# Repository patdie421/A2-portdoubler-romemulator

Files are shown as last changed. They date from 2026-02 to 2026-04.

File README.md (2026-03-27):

This card provide 2 functionalities :  
- duplicates the slot it uses into two horizontal slots (usefull in slot 7). I designed it to be able to use an A2DVI interface on Apple II computers where all the slots are occupied.  
- ROM emulation card (https://mirrors.apple2.org.za/ftp.apple.asimov.net/documentation/hardware/schematics/rom_emulator_card_050-0009-01_schematic.pdf). A friend ask me for a card capable of running Adrian Black's Deadtest ROM (https://github.com/misterblack1/appleII_deadtest). Since I had space on my slot splitter, I simply added three chips, and that was it. This first version is designed to use only the Deadtest ROM. Current restriction :
  - it did'nt allow to be controled by softwitch  
  - DMA IN/OUT are not supported (not needed when used in slot 7)  

  A version of the card currently under development will provide all the functionalities of a ROM card  
# Slot doubler  
This card is designed to allow the installation of two cards in a single slot. Although it can be installed in any slot, it is most effectively used as a splitter in slot 7. Since the two connectors are wired in parallel, not all card combinations are possible.
## kinds of Apple II cards
We can identify 3 kinds of cards :
- basic card : use soft switches, 16 addresses 0xC080+n\*0x10 to 0xC08F+n\*0x10, n=1 to 7, to interact whith the system. The card is activated by "Device Select" line.
- card with firmware locate at Cn00-CnFF (n=1 to 7), the "I/O Select" activated this kind of card when the firmware page is read or write. Most of this cards (if not all) use also soft switches at addresses C0N0x.  
- card "monitoring" the address bus (does not use device selection or I/O selection).  

## possible combinaisons

Different factors limit possible combinations :
- kind of card
- DMA or Interrupts
Other factors limit this combination, including the use of DMA and interrupt lines (/NMI and /INT).  
Before trying to install 2 cards in the doubled slots you have to know witch kind of cards you have.  

## working (tested) combinaisons
(to be done)

(usefull information can be fund here : https://grokipedia.com/page/apple_ii_peripheral_cards)

# Rom emulation card
The rom is activated when a jumper is set on JP4. Current version can only be used for Apple II deadtest ROM.  
Work is in progress to emulate all functionalities of Apple Rom Emulator Card (050-0009-01)  (https://mirrors.apple2.org.za/Apple%20II%20Documentation%20Project/Interface%20Cards/ROM%20Cards/Apple%20ROM%20Emulator%20Card/Photos/Apple%20ROM%20Card%20with%20ROM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))

2764 or 27128 Eprom (or pinout equivalent) can be used. Check Adrian's documentation for burning the ROM. Not that for 8K ROM (2764) you have to load into address $1800 or for 16K ROM (27128) to $3800.

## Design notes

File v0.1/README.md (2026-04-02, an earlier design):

~~Tested, working.~~ Issues were reported. Debugging in progress (thanks Daniel)  
Warning: Installation in some IIe will be difficult for card in upper slot.

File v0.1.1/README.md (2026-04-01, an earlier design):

Update connector positions  
  
 Not tested now

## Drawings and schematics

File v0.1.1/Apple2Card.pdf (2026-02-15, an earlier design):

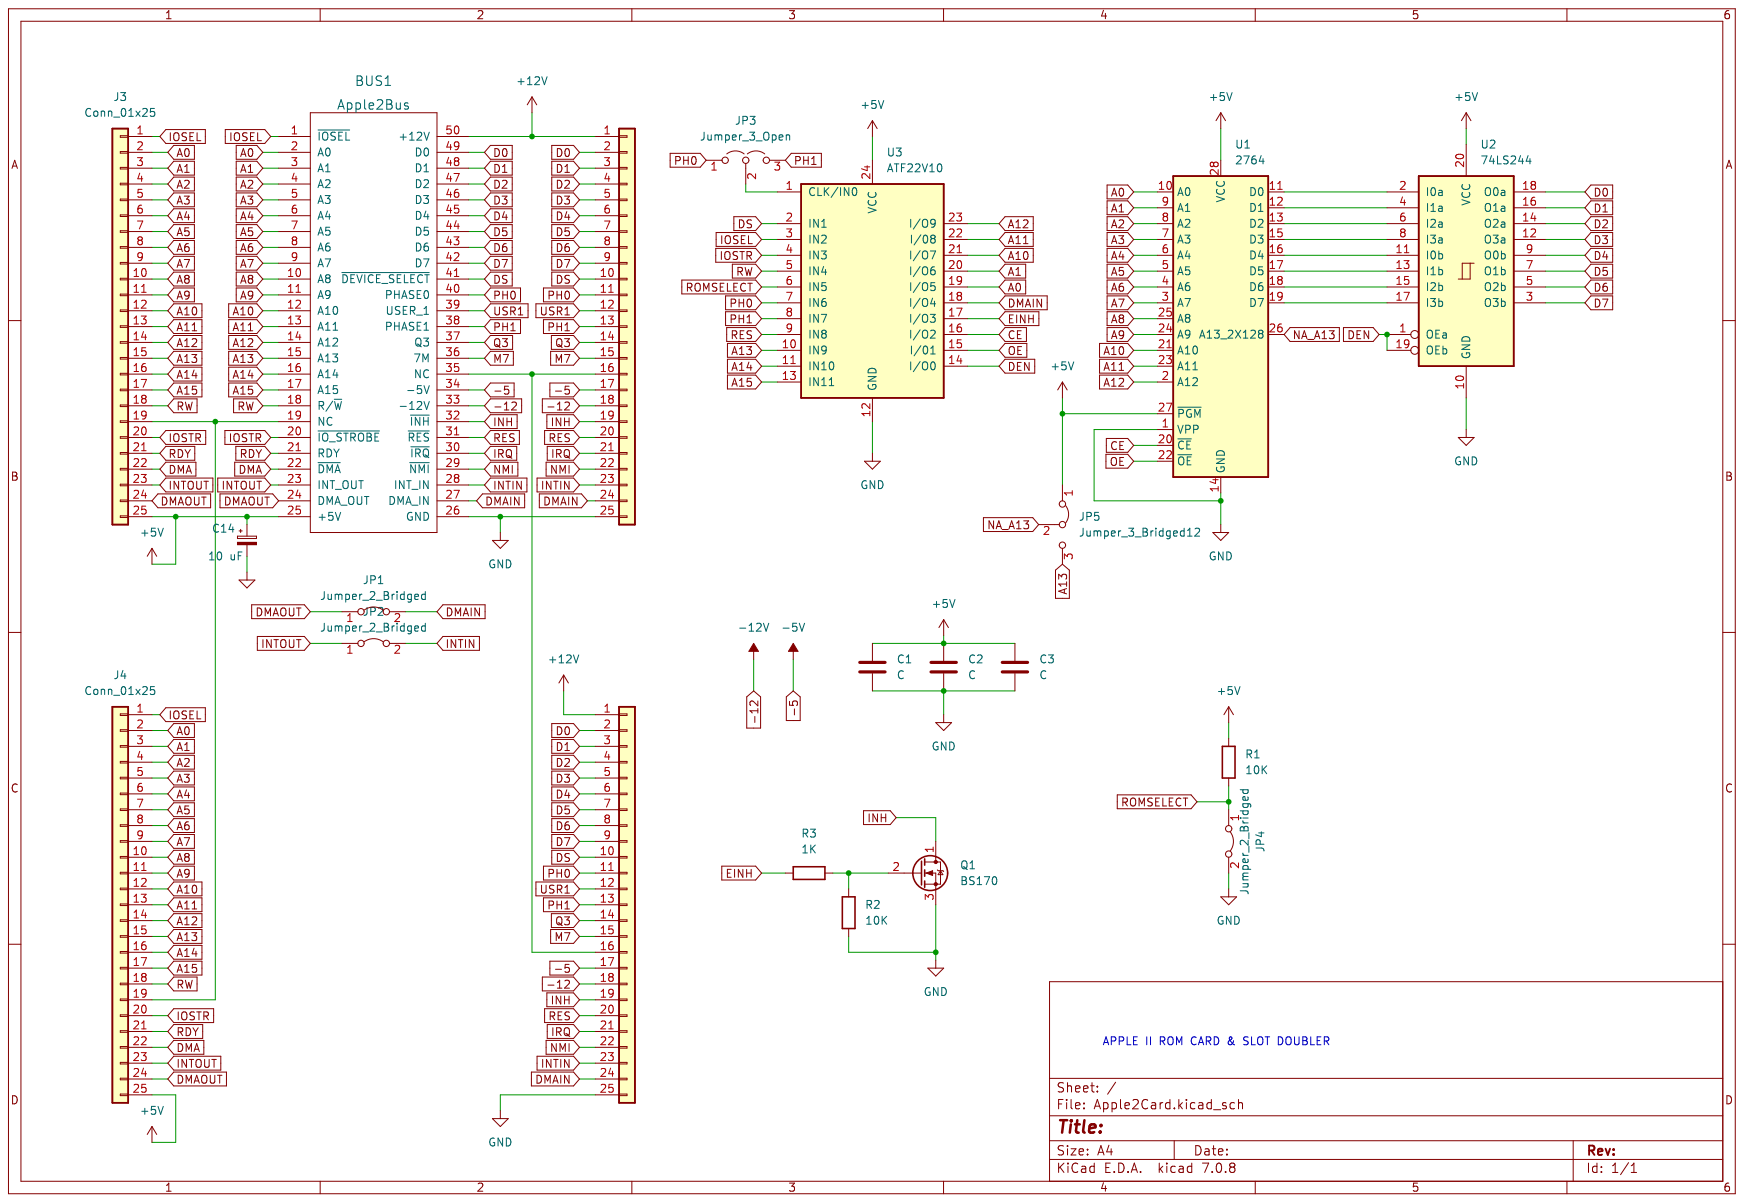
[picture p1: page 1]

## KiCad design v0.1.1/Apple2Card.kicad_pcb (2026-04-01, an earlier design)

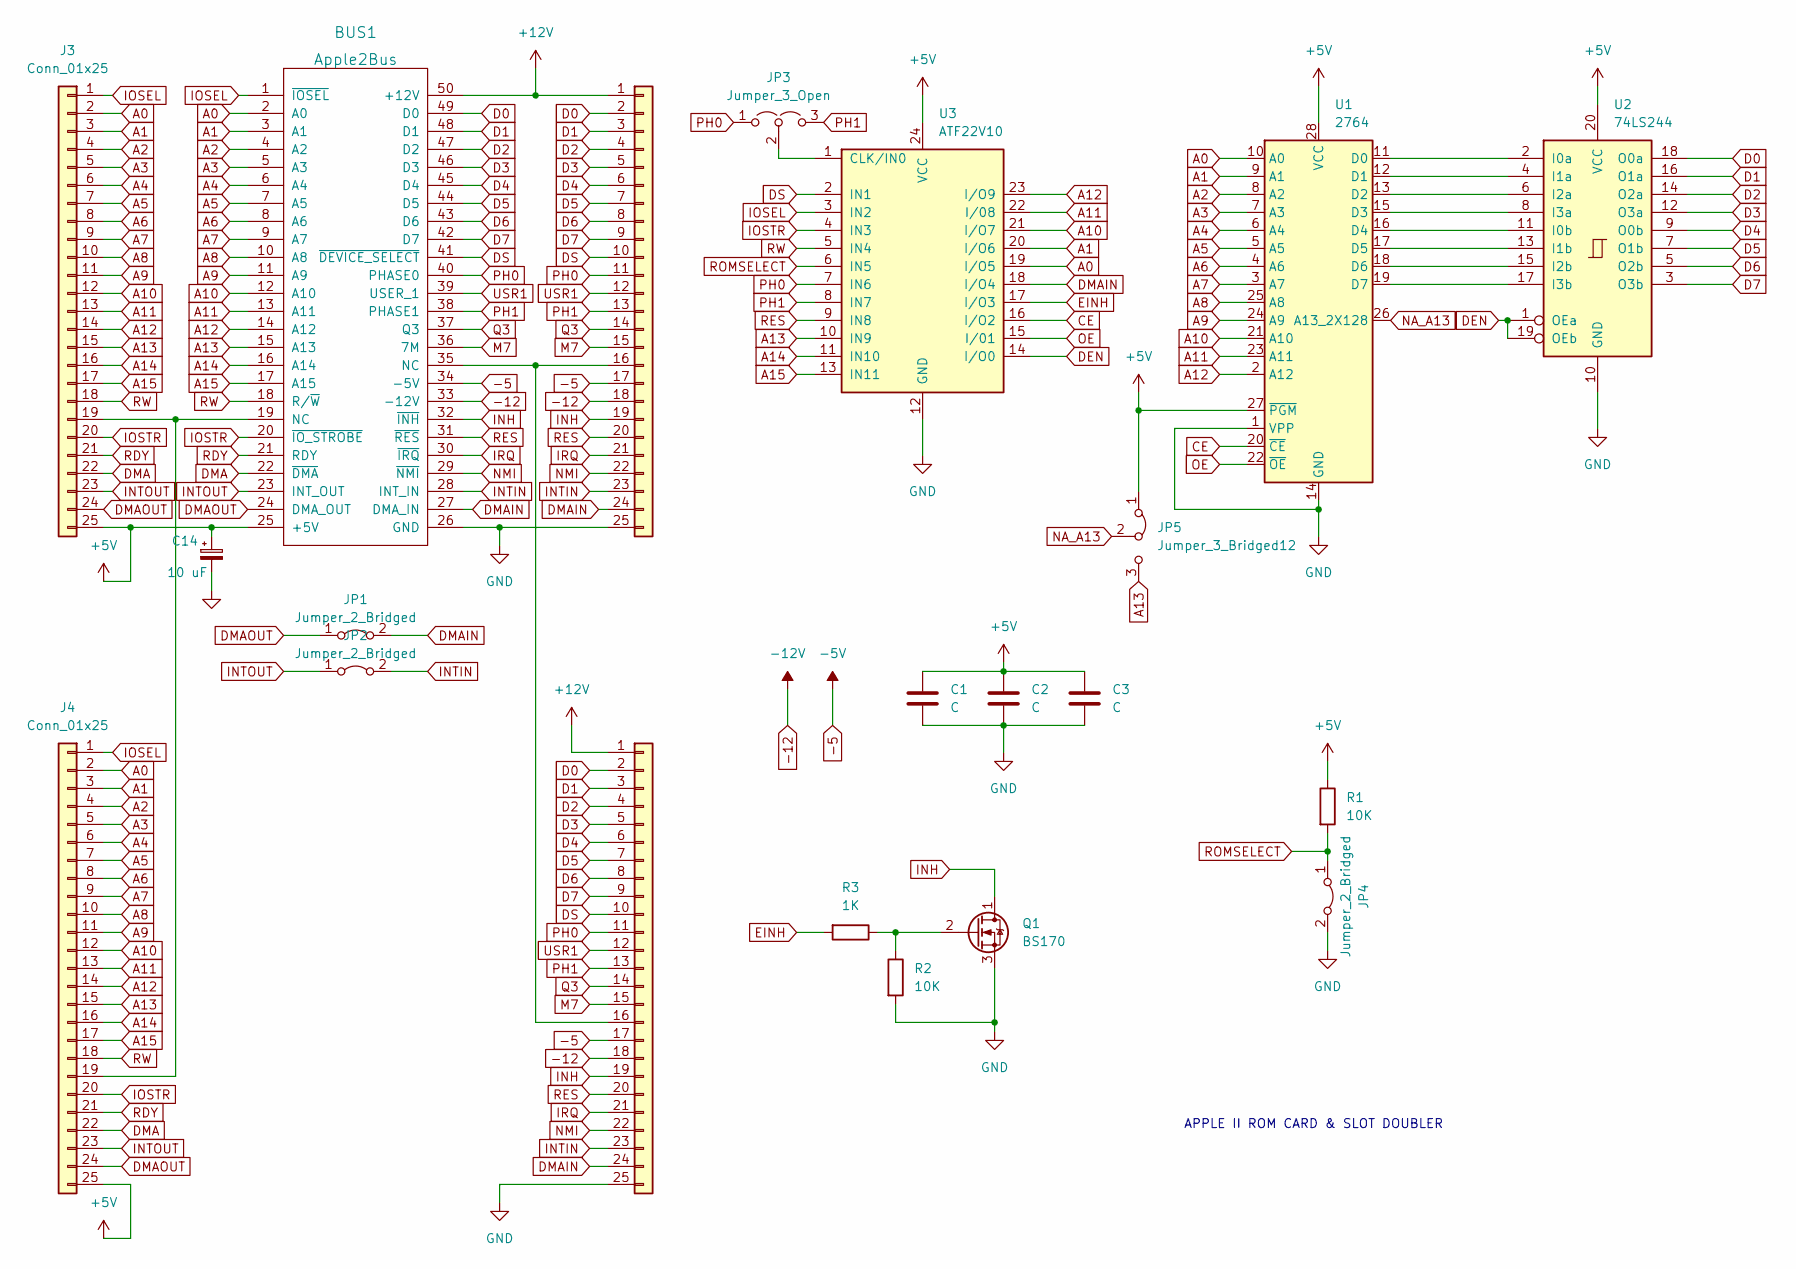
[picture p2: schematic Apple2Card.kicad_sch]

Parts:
BUS1: Apple2Bus; Apple2Slot
C1, C2, C3: C; C_Disc_D4.7mm_W2.5mm_P5.00mm
C14: 10 uF; CP_Radial_D5.0mm_P2.50mm
J1, J2, J3, J4: Conn_01x25; PinHeader_1x25_P2.54mm_Vertical
JP1, JP2, JP4: Jumper_2_Bridged; PinHeader_1x02_P2.54mm_Vertical
JP3: Jumper_3_Open; PinHeader_1x03_P2.54mm_Vertical
JP5: Jumper_3_Bridged12; SolderJumper-3_P1.3mm_Bridged12_RoundedPad1.0x1.5mm
Q1: BS170; TO-92_Inline
R1, R2: 10K; R_Axial_DIN0204_L3.6mm_D1.6mm_P7.62mm_Horizontal
R3: 1K; R_Axial_DIN0204_L3.6mm_D1.6mm_P7.62mm_Horizontal
U1: 2764; DIP-28_W15.24mm
U2: 74LS244; DIP-20_W7.62mm_Socket
U3: ATF22V10; DIP-24_W7.62mm_Socket

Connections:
+5V: BUS1.25 (+5V), C1.1, C2.1, C3.1, C14.1, J3.25, J4.25, JP5.1 (A), R1.1, U1.27 (~PGM), U1.28 (VCC), U2.20 (VCC), U3.24 (VCC)
+12V: BUS1.50 (+12V), J1.1, J2.1
-5: BUS1.34 (-5V), J1.17, J2.17
-12: BUS1.33 (-12V), J1.18, J2.18
A0: BUS1.2 (A0), J3.2, J4.2, U1.10 (A0), U3.19 (I/O5)
A1: BUS1.3 (A1), J3.3, J4.3, U1.9 (A1), U3.20 (I/O6)
A2: BUS1.4 (A2), J3.4, J4.4, U1.8 (A2)
A3: BUS1.5 (A3), J3.5, J4.5, U1.7 (A3)
A4: BUS1.6 (A4), J3.6, J4.6, U1.6 (A4)
A5: BUS1.7 (A5), J3.7, J4.7, U1.5 (A5)
A6: BUS1.8 (A6), J3.8, J4.8, U1.4 (A6)
A7: BUS1.9 (A7), J3.9, J4.9, U1.3 (A7)
A8: BUS1.10 (A8), J3.10, J4.10, U1.25 (A8)
A9: BUS1.11 (A9), J3.11, J4.11, U1.24 (A9)
A10: BUS1.12 (A10), J3.12, J4.12, U1.21 (A10), U3.21 (I/O7)
A11: BUS1.13 (A11), J3.13, J4.13, U1.23 (A11), U3.22 (I/08)
A12: BUS1.14 (A12), J3.14, J4.14, U1.2 (A12), U3.23 (I/O9)
A13: BUS1.15 (A13), J3.15, J4.15, JP5.3 (B), U3.10 (IN9)
A14: BUS1.16 (A14), J3.16, J4.16, U3.11 (IN10)
A15: BUS1.17 (A15), J3.17, J4.17, U3.13 (IN11)
CE: U1.20 (~CE), U3.16 (I/O2)
D0: BUS1.49 (D0), J1.2, J2.2, U2.18 (O0a)
D1: BUS1.48 (D1), J1.3, J2.3, U2.16 (O1a)
D2: BUS1.47 (D2), J1.4, J2.4, U2.14 (O2a)
D3: BUS1.46 (D3), J1.5, J2.5, U2.12 (O3a)
D4: BUS1.45 (D4), J1.6, J2.6, U2.9 (O0b)
D5: BUS1.44 (D5), J1.7, J2.7, U2.7 (O1b)
D6: BUS1.43 (D6), J1.8, J2.8, U2.5 (O2b)
D7: BUS1.42 (D7), J1.9, J2.9, U2.3 (O3b)
DEN: U2.1 (OEa), U2.19 (OEb), U3.14 (I/O0)
DMA: BUS1.22 (~DMA), J3.22, J4.22
DMAIN: BUS1.27 (DMA_IN), J1.24, J2.24, JP1.2 (B), U3.18 (I/O4)
DMAOUT: BUS1.24 (DMA_OUT), J3.24, J4.24, JP1.1 (A)
DS: BUS1.41 (~DEVICE_SELECT), J1.10, J2.10, U3.2 (IN1)
EINH: R3.2, U3.17 (I/O3)
GND: BUS1.26 (GND), C1.2, C2.2, C3.2, C14.2, J1.25, J2.25, JP4.2 (B), Q1.3 (S), R2.2, U1.1 (VPP), U1.14 (GND), U2.10 (GND), U3.12 (GND)
INH: BUS1.32 (~INH), J1.19, J2.19, Q1.1 (D)
INTIN: BUS1.28 (INT_IN), J1.23, J2.23, JP2.2 (B)
INTOUT: BUS1.23 (INT_OUT), J3.23, J4.23, JP2.1 (A)
IOSEL: BUS1.1 (~IOSEL), J3.1, J4.1, U3.3 (IN2)
IOSTR: BUS1.20 (~IO_STROBE), J3.20, J4.20, U3.4 (IN3)
IRQ: BUS1.30 (~IRQ), J1.21, J2.21
M7: BUS1.36 (7M), J1.15, J2.15
NA_A13: JP5.2 (C), U1.26 (A13_2X128)
NMI: BUS1.29 (~NMI), J1.22, J2.22
unnamed: BUS1.35 (NC), J1.16, J2.16
unnamed: BUS1.19 (NC), J3.19, J4.19
unnamed: JP3.2 (C), U3.1 (CLK/IN0)
unnamed: Q1.2 (G), R2.1, R3.1
unnamed: U1.11 (D0), U2.2 (I0a)
unnamed: U1.12 (D1), U2.4 (I1a)
unnamed: U1.13 (D2), U2.6 (I2a)
unnamed: U1.15 (D3), U2.8 (I3a)
unnamed: U1.16 (D4), U2.11 (I0b)
unnamed: U1.17 (D5), U2.13 (I1b)
unnamed: U1.18 (D6), U2.15 (I2b)
unnamed: U1.19 (D7), U2.17 (I3b)
OE: U1.22 (~OE), U3.15 (I/01)
PH0: BUS1.40 (PHASE0), J1.11, J2.11, JP3.1 (A), U3.7 (IN6)
PH1: BUS1.38 (PHASE1), J1.13, J2.13, JP3.3 (B), U3.8 (IN7)
Q3: BUS1.37 (Q3), J1.14, J2.14
RDY: BUS1.21 (RDY), J3.21, J4.21
RES: BUS1.31 (~RES), J1.20, J2.20, U3.9 (IN8)
RW: BUS1.18 (R/~W), J3.18, J4.18, U3.5 (IN4)
USR1: BUS1.39 (USER_1), J1.12, J2.12
/ROMSELECT: JP4.1 (A), R1.2, U3.6 (IN5)

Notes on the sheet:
APPLE II ROM CARD & SLOT DOUBLER

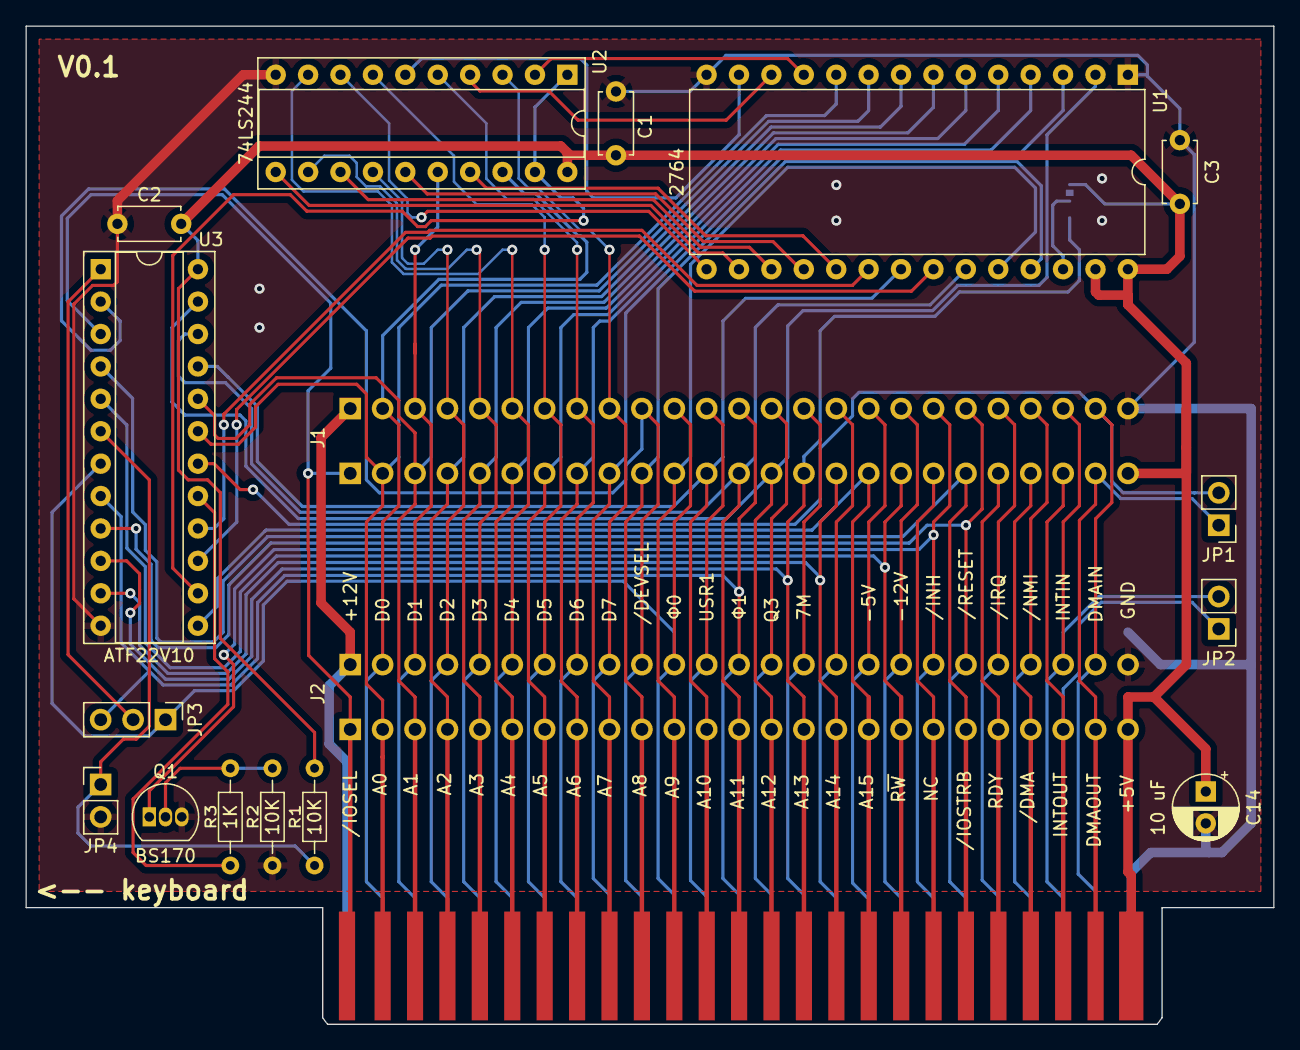
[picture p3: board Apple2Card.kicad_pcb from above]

Board: 2 copper layers, 97.8 x 78.2 mm, 21 parts (1 on the bottom side), 66 nets.

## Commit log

2026-04-01 spacement correction
    [Apple2Card-B_Cu.gbr, Apple2Card-B_Mask.gbr, Apple2Card-B_Silkscreen.gbr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]
2026-04-01 remove not relevant files
    [Apple2Card-B_Cu.gbr, Apple2Card-B_Mask.gbr, Apple2Card-B_Silkscreen.gbr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]
